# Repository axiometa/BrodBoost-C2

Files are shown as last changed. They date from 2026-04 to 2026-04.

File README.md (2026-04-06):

# BrodBoost-C2

BrødBoost-C2 is a project of Axiometa, it is available for sale at [axiometa.io](https://www.axiometa.io/products/axiometa-brodboost-c2-breadboard-power-supply)

BrødBoost-C2 is a USB-C breadboard power supply that delivers clean 5V and 3.3V power directly to your breadboard. It features short-circuit fuse protection, USB ESD protection, an ideal diode for reverse polarity safety, a load switch with soft startup, and ferrite bead filtering for low-noise operation. An on/off switch and power LED keep you in control, while USB data passthrough keeps your lines accessible.

169_bbs0004

# Overview
Overview_BBS0004

# Compatibility
Dimensions_BBS0004

# Voltage Selection
Both voltage rails can be independently selected or simultaneously set to 5.0 V or 3.3 V by moving around the jumper cap. Although the jumper cap design has received mixed opinions, it is implemented here as a safety feature and to be cautios of BOM. The design requires deliberate jumper cap movement, which helps prevent accidental voltage changes from 3.3 V to 5.0 V that might occur if a switch were used.
HOWto_BBS0004

# Schematic
A USB-C receptacle accepts a standard USB-C cable. The CC1 and CC2 lines are pulled to ground through 5.1 kΩ resistors to negotiate 5 V from the host. Power flows through a ferrite bead for noise suppression, a 1 A polyfuse for short-circuit protection, and decoupling capacitors.
An ideal diode provides reverse polarity and overvoltage protection. A load switch with controlled soft startup prevents inrush current. The power switch and red power LED sit in series on the main rail. USB ESD protection is included on the data and power lines.
Step-down conversion from 5 V to 3.3 V is handled by the AP2114H-3.3TRG1 LDO regulator. Both voltage outputs are routed to 1×3 2.54 mm headers for rail selection. A separate header provides access to 5 V, 3.3 V, ground, and USB data lines.


# PCB Design
BrodBoost-C2 is a two-layer PCB measuring 12 mm by 54.0 mm, designed to maximize trace width and optimize the switching regulator's ground return path. This layout comfortably supports the nominal device current of approximately 1 A.

**Top**
T_BBS0004
**Bottom**
B_BBS0004

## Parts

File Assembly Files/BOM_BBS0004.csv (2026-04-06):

Designator | Footprint | Quantity | Value | LCSC Part #
C13,C8,C1 | 805 | 3 | 10uF | C15850
C14 | 805 | 1 | 22uF | C45783
C2, C4, C5 | 805 | 3 | 10 uF | C15850
C3, C7 | 805 | 2 | 100nF | C49678
C6 | 603 | 1 | 10nF | C57112
D2 | SOT-143 | 1 | PRTR5V0U2X | C5158049
D3 | 603 | 1 | Red | C965799
F1 | 603 | 1 | Polyfuse | C18203128
FB1 | 805 | 1 | Ferrite Bead | C85840
J1, J2 | PinHeader_2x03_P2.54mm_Vertical_SMD | 2 | Bottom | C3294461
J3, J4 | PinHeader_1x03_P2.54mm_Vertical | 2 | Select | C5360899
P1 | USB-C-16Pin | 1 |  | C2927038
R10, R5 | 603 | 2 | 5.1k | C23186
R3, R4 | 402 | 2 | 5.1k | C25905
R6 | 603 | 1 | 100 | C22775
U1 | TPS22918 | 1 | TPS22918 | C131941
U10 | SOT-363_SC-70-6 | 1 | LM66100DCK | C2869734
U2 | on/off switch | on/off switch | on/off switch | C2939725 | or side: C50878478
U3 | SOT-223-3_TabPin2 | 1 | AP2114H-3.3TRG1 | C150716

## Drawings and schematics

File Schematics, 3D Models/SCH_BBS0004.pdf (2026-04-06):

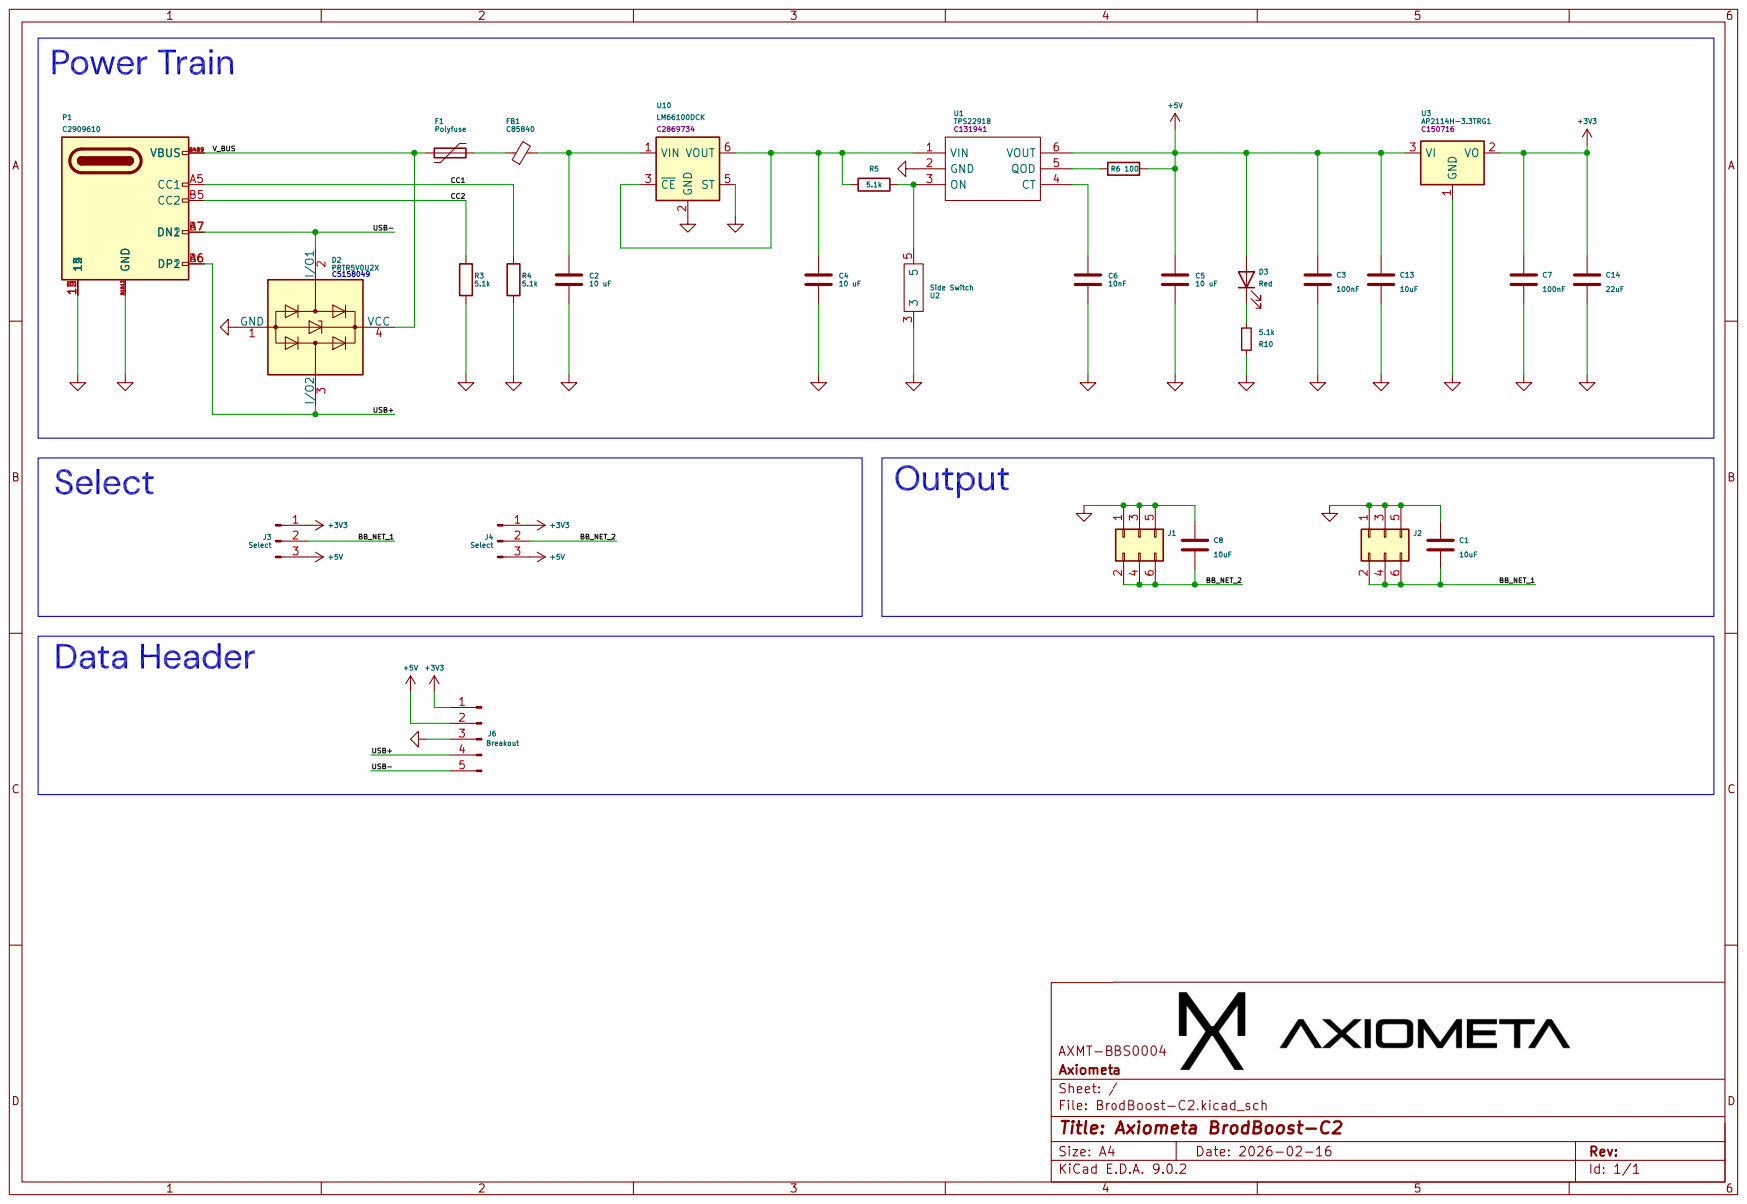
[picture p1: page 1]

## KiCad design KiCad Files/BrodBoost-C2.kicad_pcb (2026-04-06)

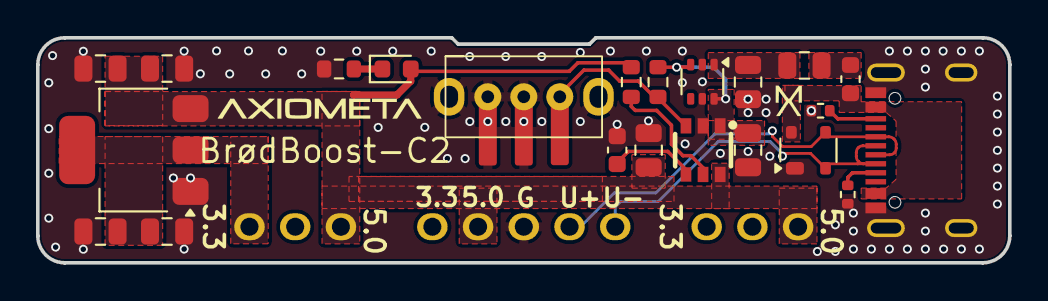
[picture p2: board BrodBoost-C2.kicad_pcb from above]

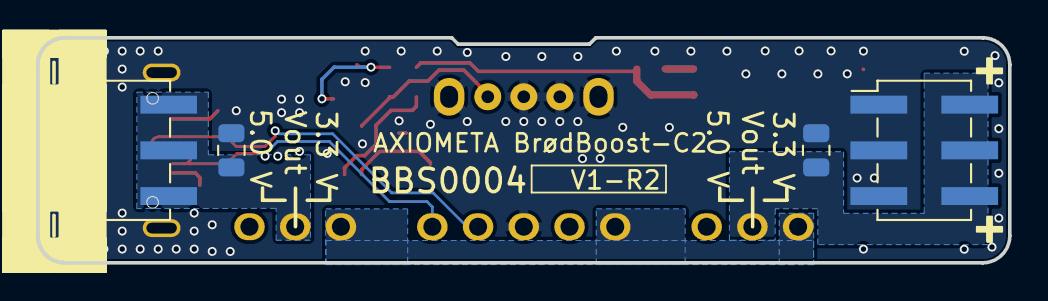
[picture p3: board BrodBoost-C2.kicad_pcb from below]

Board: 2 copper layers, 54.0 x 12.5 mm, 29 parts (4 on the bottom side), 17 nets.

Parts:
C1, C8, C13: 10uF; C_0805_2012Metric
C2, C4, C5: 10 uF; C_0805_2012Metric
C3, C7: 100nF; C_0805_2012Metric
C6: 10nF; C_0603_1608Metric
C14: 22uF; C_0805_2012Metric
D2: PRTR5V0U2X; SOT-143
D3: Red; LED_0603_1608Metric
F1: Polyfuse; Fuse_0603_1608Metric
FB1: C85840; C_0805_2012Metric
J1, J2: Conn_02x02_Counter_Clockwise; PinHeader_2x03_P2.54mm_Vertical_SMD
J3, J4: Select; PinHeader_1x03_P2.54mm_Vertical
J6: Breakout; PinHeader_1x05_P2.54mm_Horizontal
P1: C2909610; USB-C-16Pin-Orange
R3, R4: 5.1k; R_0402_1005Metric
R5, R10: 5.1k; R_0603_1608Metric
R6: 100; R_0603_1608Metric
U1: TPS22918
U2: Side Switch; TO-92_Inline_Wide
U3: AP2114HA-3.3TRG1; SOT-223-3_TabPin2
U10: LM66100DCK; SOT-363_SC-70-6

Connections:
+3V3: C7.1, C14.1, J3.1, J4.1, J6.1, U3.2 (VO)
+5V: C3.1, C5.1, C13.1, D3.2 (A), J3.3, J4.3, J6.2, R6.2, U1.6 (VOUT), U3.3 (VI)
/BB_NET_1: C1.2, J2.2, J2.4, J2.6, J3.2
/BB_NET_2: C8.2, J1.2, J1.4, J1.6, J4.2
/CC1: P1.A5 (CC1), R4.2
/CC2: P1.B5 (CC2), R3.2
/USB+: D2.3 (I/O2), J6.4, P1.A6 (DP1), P1.B6 (DP2)
/USB-: D2.2 (I/O1), J6.5, P1.A7 (DN1), P1.B7 (DN2)
/V_BUS: D2.4 (VCC), F1.1, P1.A4B9 (VBUS), P1.B4A9 (VBUS)
GND: C1.1, C2.2, C3.2, C4.2, C5.2, C6.2, C7.2, C8.1, C13.2, C14.2, D2.1 (GND), J1.1, J1.3, J1.5, J2.1, J2.3, J2.5, J6.3, P1.12, P1.13, P1.14, P1.15, P1.A1B12 (GND), P1.B1A12 (GND), R3.1, R4.1, R10.2, U1.2 (GND), U2.3, U3.1 (GND), U10.2 (GND), U10.5 (ST)
unnamed: D3.1 (K), R10.1
unnamed: F1.2, FB1.1
unnamed: C6.1, U1.4 (CT)
unnamed: R5.2, U1.3 (ON), U2.5
unnamed: R6.1, U1.5 (QOD)
unnamed: C4.1, R5.1, U1.1 (VIN), U10.3 (~CE), U10.6 (VOUT)
unnamed: C2.1, FB1.2, U10.1 (VIN)
